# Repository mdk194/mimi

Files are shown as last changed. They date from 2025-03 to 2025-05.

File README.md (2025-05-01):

# mimi keyboard

54 keys split keyboard.
reversible pcb and 3d printed cases

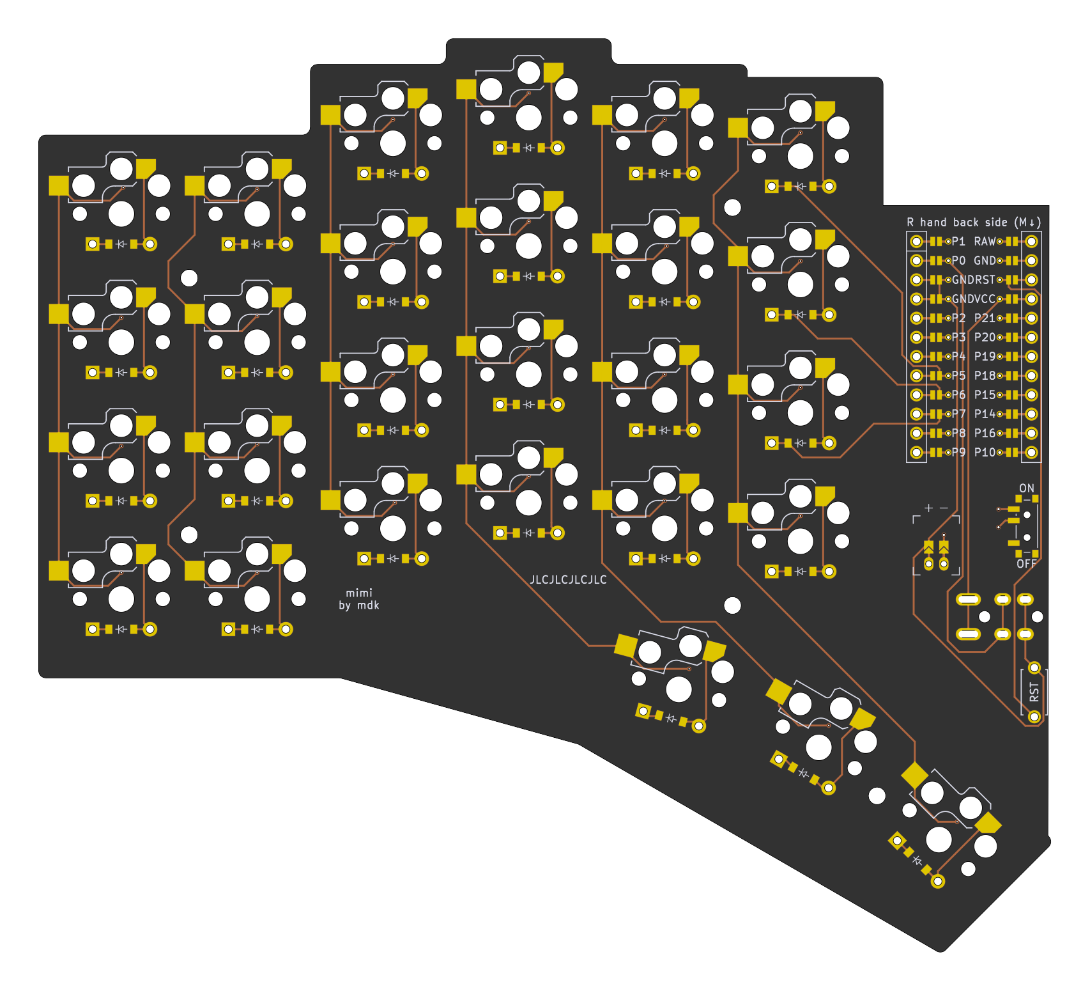
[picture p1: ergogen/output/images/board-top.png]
top pcb

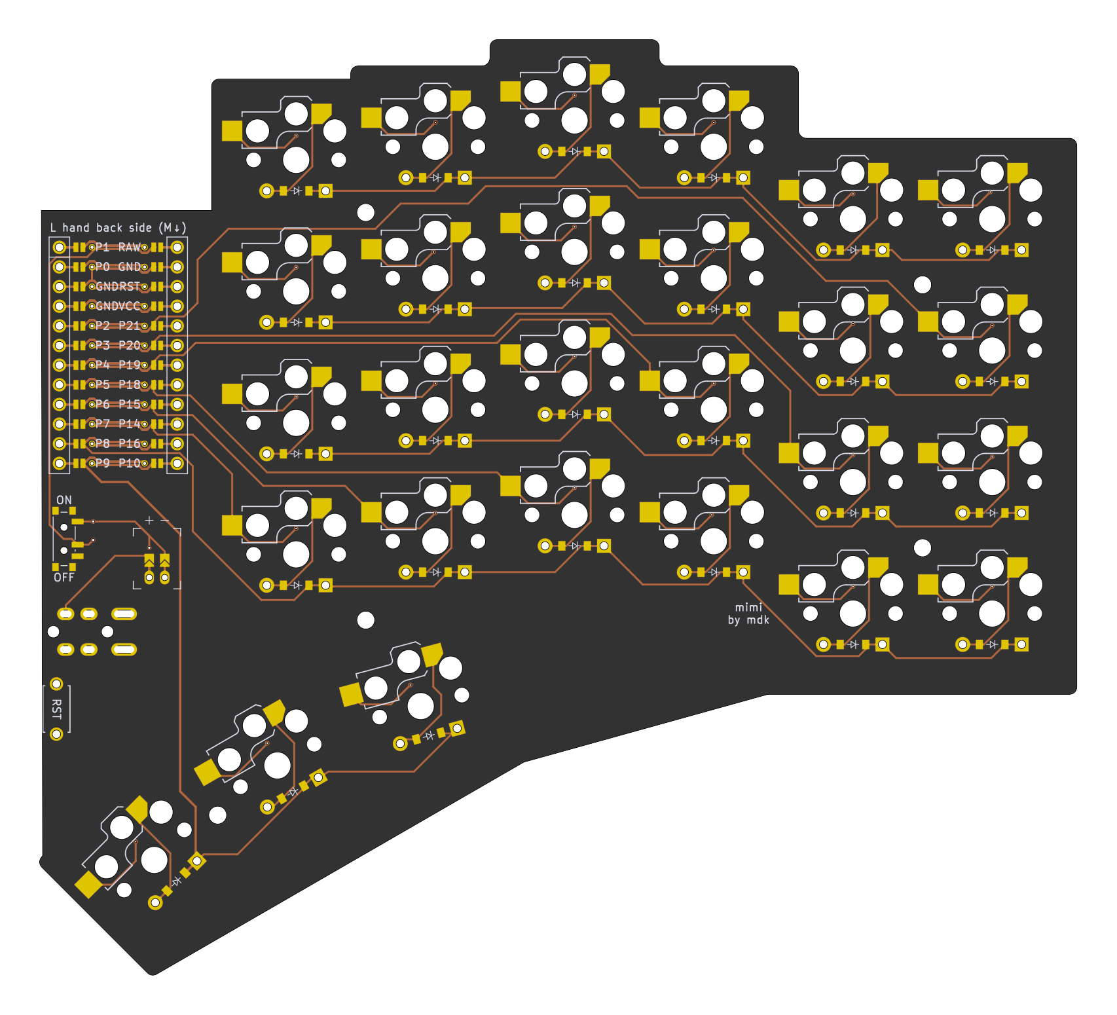
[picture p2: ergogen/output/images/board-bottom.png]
bottom pcb


# ZMK
- main branch: left side as master
- dongle branch: include config for dongle

# TODO
- qmk firmware
- test trrs socket

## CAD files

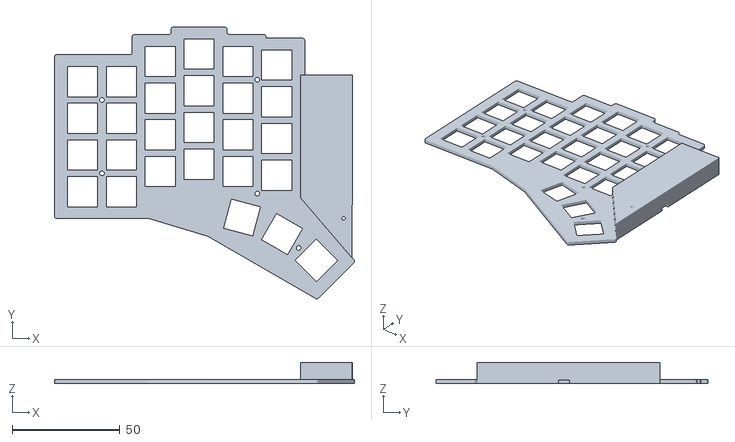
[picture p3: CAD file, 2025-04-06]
cases/wl_top.stl
139.0 x 125.9 x 9.80

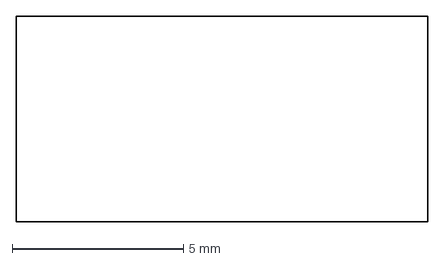
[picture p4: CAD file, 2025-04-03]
output/outlines/usb.dxf
12.0 x 6.00 mm

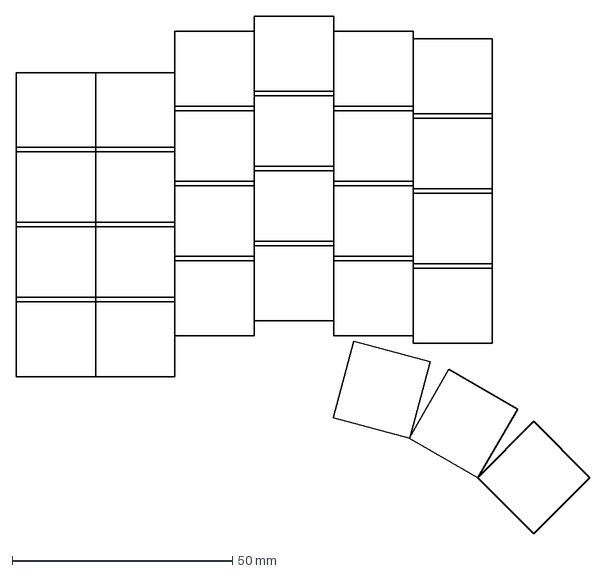
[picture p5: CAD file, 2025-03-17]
output/points/demo.dxf
130.1 x 117.3 mm

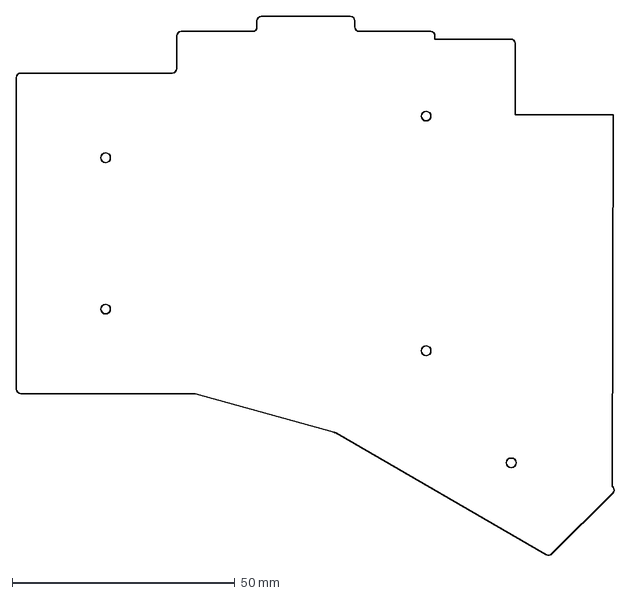
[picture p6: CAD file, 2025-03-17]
output/outlines/pcb.dxf
134.3 x 121.2 mm

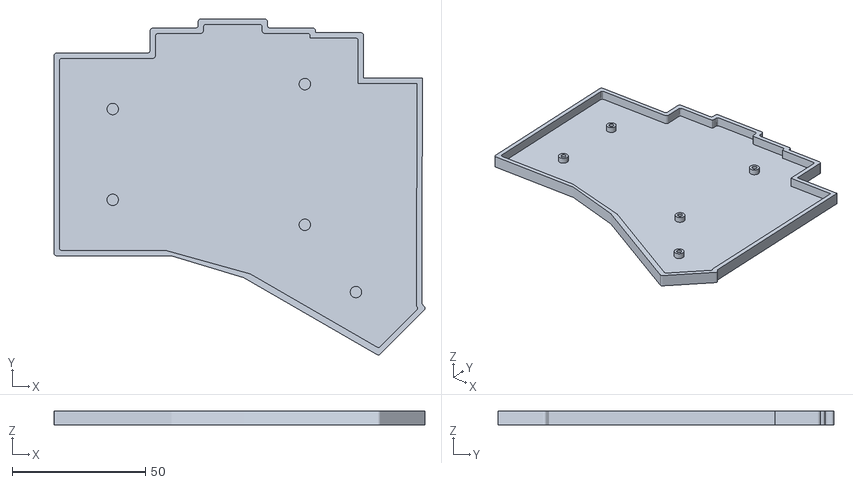
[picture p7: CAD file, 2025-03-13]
cases/bottom.stl
139.0 x 125.9 x 5.20

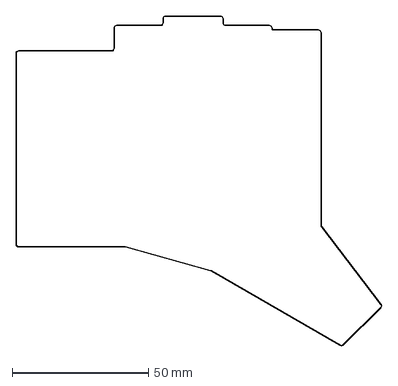
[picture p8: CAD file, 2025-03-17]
output/outlines/base.dxf
134.3 x 121.2 mm

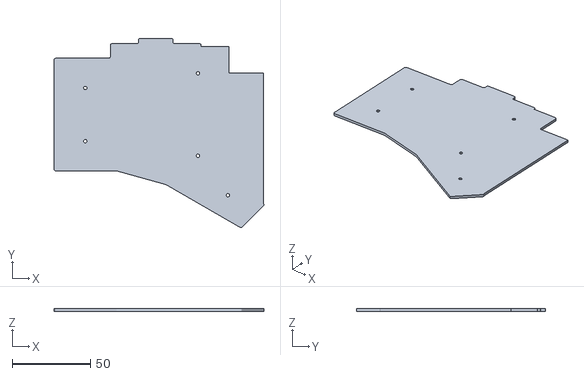
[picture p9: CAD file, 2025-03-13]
cases/pcb.stl
134.2 x 121.1 x 1.60

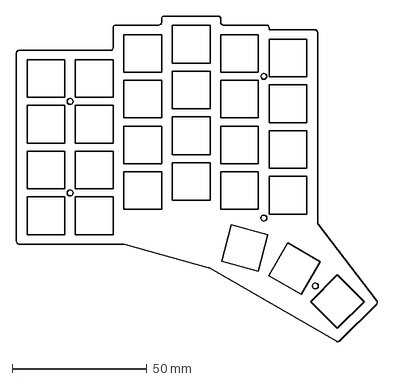
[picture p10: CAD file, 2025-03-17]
output/outlines/top_plate.dxf
134.3 x 121.2 mm

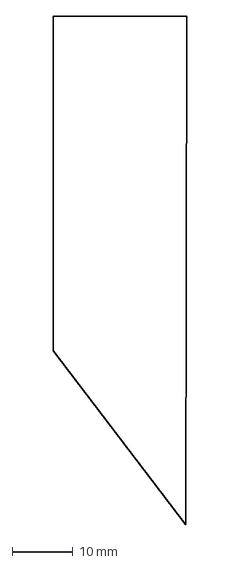
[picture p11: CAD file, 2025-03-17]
output/outlines/controller_area.dxf
22.0 x 83.7 mm

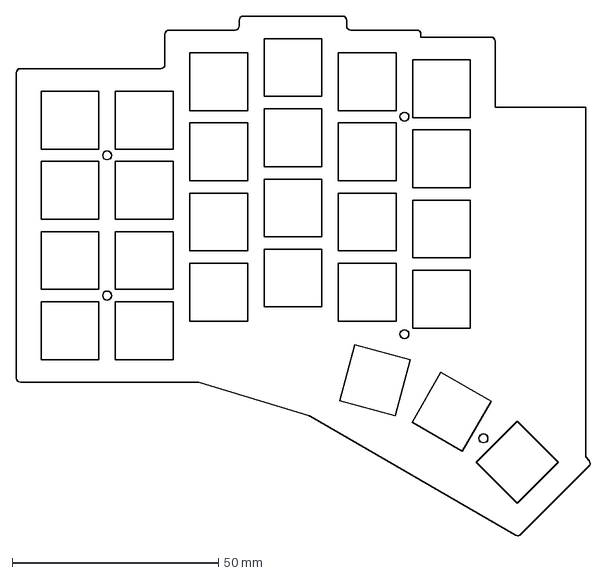
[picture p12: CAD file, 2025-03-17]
output/outlines/top_case.dxf
139.1 x 126.0 mm

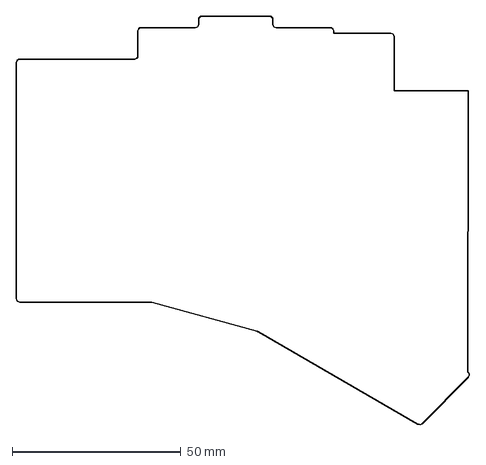
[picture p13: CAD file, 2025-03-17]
output/outlines/bottom_case.dxf
134.3 x 121.2 mm

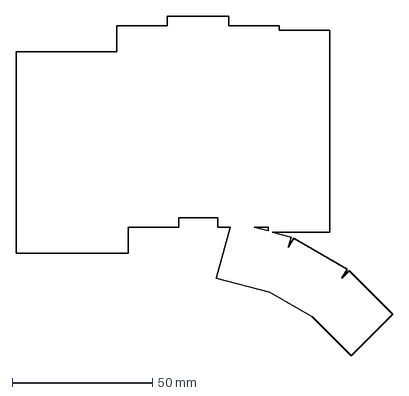
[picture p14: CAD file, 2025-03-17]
output/outlines/raw.dxf
134.6 x 121.3 mm

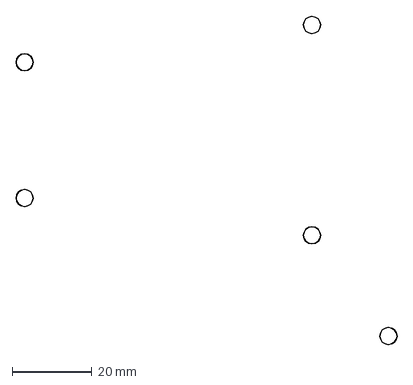
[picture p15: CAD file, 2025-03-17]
output/outlines/standoff.dxf
95.4 x 82.2 mm

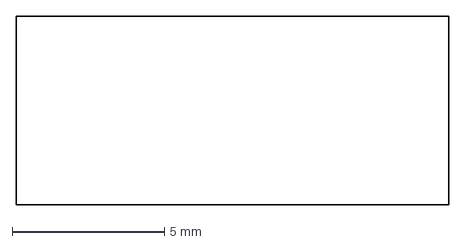
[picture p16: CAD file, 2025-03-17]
output/outlines/trrs.dxf
14.2 x 6.20 mm

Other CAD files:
cases/top.stl
output/outlines/inner_top_cover_area.dxf
output/outlines/xlbase.dxf
output/outlines/xlbottom_case.dxf
output/outlines/power.dxf
output/outlines/screw_holes.dxf
output/outlines/switches.dxf
output/outlines/top_cover_area.dxf
output/outlines/xlcontroller_area.dxf
output/outlines/xlpcb.dxf

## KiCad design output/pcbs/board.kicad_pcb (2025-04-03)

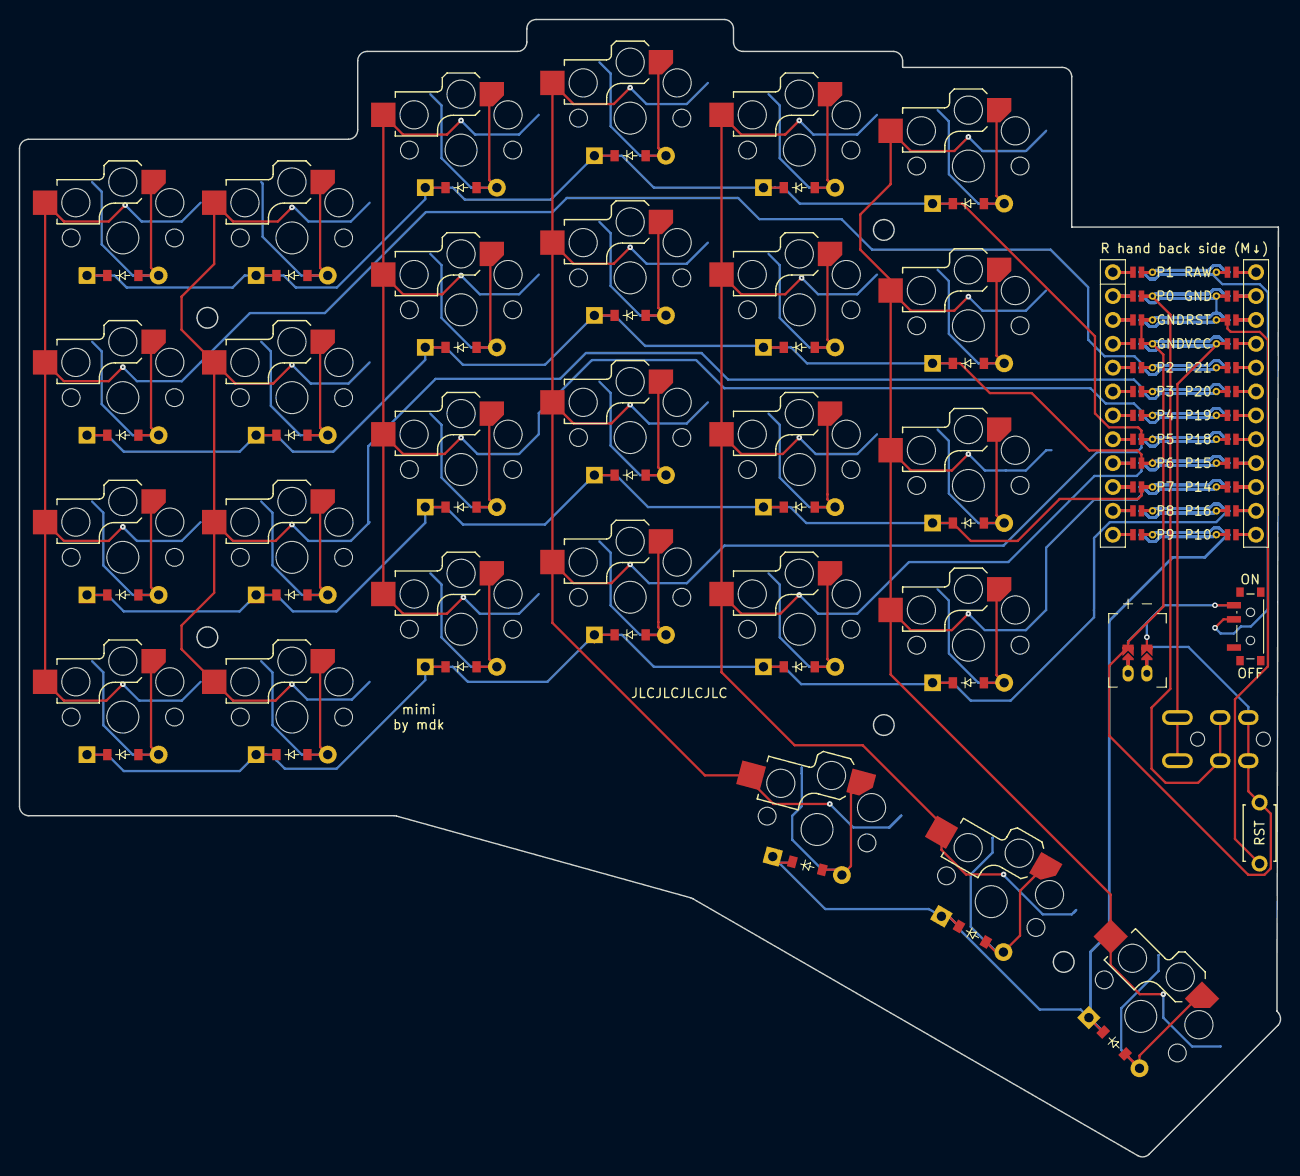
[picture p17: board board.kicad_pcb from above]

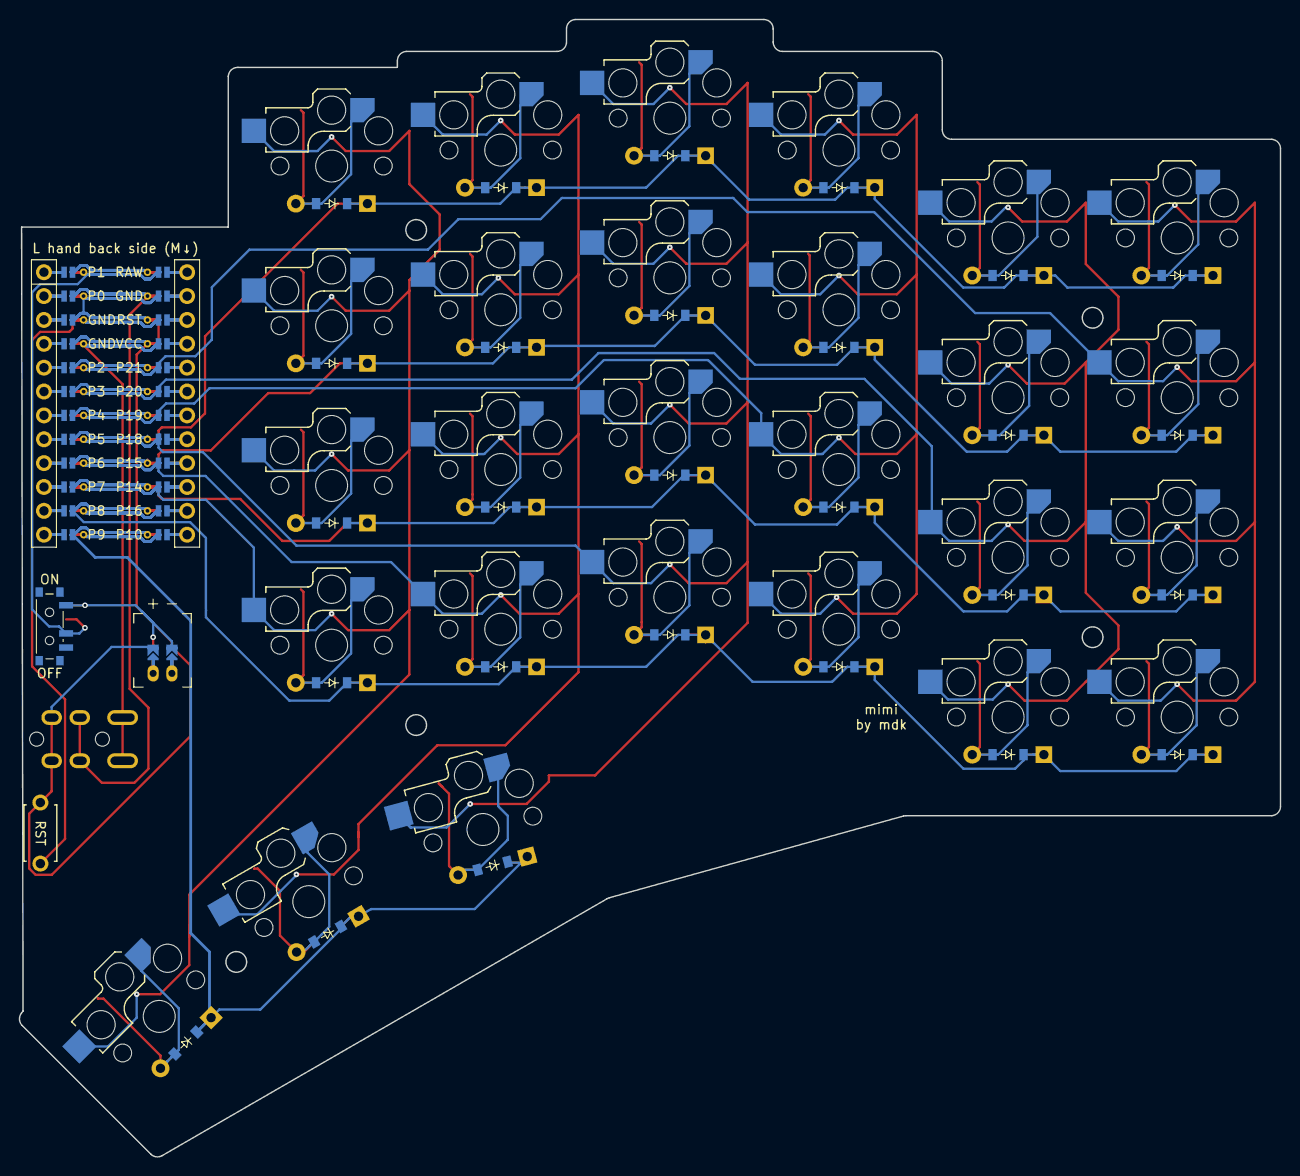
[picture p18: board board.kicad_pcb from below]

Board: 2 copper layers, 134.2 x 121.1 mm, 59 parts (27 on the bottom side), 46 nets.

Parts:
D1, D2, D3, D4, D5, D6, D7, D8, D9, D10, D11, D12, D13, D14, D15, D16, D17, D18, D19, D20, D21, D22, D23, D24, D25, D26, D27: diode_tht_sod123
JST1: battery_connector_jst_ph_2
MCU1: mcu_nice_nano
PWR1: power_switch_smd_side
RST1: reset_switch_tht_top
S1, S2, S3, S4, S5, S6, S7, S8, S9, S10, S11, S12, S13, S14, S15, S16, S17, S18, S19, S20, S21, S22, S23, S24, S25, S26, S27: switch_choc_v1_v2
TRRS1: trrs_pj320a (reversible, symmetric)

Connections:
BAT_P: JST1.1, PWR1.1, PWR1.3
GND: JST1.2, MCU1.102, MCU1.121, MCU1.122, RST1.2, TRRS1.2
JST1_1: JST1.11, JST1.21, JST1.31
JST1_2: JST1.12, JST1.22, JST1.32
P0: MCU1.123, TRRS1.3
P5: D4.1, D8.1, D12.1, D16.1, D20.1, D24.1, MCU1.117
P6: D3.1, D7.1, D11.1, D15.1, D19.1, D23.1, MCU1.116
P7: D2.1, D6.1, D10.1, D14.1, D18.1, D22.1, MCU1.115
P8: D1.1, D5.1, D9.1, D13.1, D17.1, D21.1, MCU1.114
P9: D25.1, D26.1, D27.1, MCU1.113
P14: MCU1.110, S21.2, S22.2, S23.2, S24.2, S27.2
P15: MCU1.109, S17.2, S18.2, S19.2, S20.2, S26.2
P18: MCU1.108, S13.2, S14.2, S15.2, S16.2, S25.2
P19: MCU1.107, S9.2, S10.2, S11.2, S12.2
P20: MCU1.106, S5.2, S6.2, S7.2, S8.2
P21: MCU1.105, S1.2, S2.2, S3.2, S4.2
RAW: MCU1.101, PWR1.2
RST: MCU1.103, RST1.1
VCC: MCU1.104, TRRS1.4
far_thumb: D27.2, S27.1
home_thumb: D26.2, S26.1
index_bottom: D17.2, S17.1
index_home: D18.2, S18.1
index_number: D20.2, S20.1
index_top: D19.2, S19.1
inner_bottom: D21.2, S21.1
inner_home: D22.2, S22.1
inner_number: D24.2, S24.1
inner_top: D23.2, S23.1
middle_bottom: D13.2, S13.1
middle_home: D14.2, S14.1
middle_number: D16.2, S16.1
middle_top: D15.2, S15.1
near_thumb: D25.2, S25.1
outer_bottom: D1.2, S1.1
outer_home: D2.2, S2.1
outer_number: D4.2, S4.1
outer_top: D3.2, S3.1
pinky_bottom: D5.2, S5.1
pinky_home: D6.2, S6.1
pinky_number: D8.2, S8.1
pinky_top: D7.2, S7.1
ring_bottom: D9.2, S9.1
ring_home: D10.2, S10.1
ring_number: D12.2, S12.1
ring_top: D11.2, S11.1

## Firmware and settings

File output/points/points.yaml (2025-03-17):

matrix_outer_bottom:
    x: 50
    'y': -150
    r: 0
    meta:
        stagger: 0
        spread: 18
        splay: 0
        origin:
            - 0
            - 0
        orient: 0
        shift:
            - 0
            - 0
        rotate: 0
        adjust: {}
        width: 18
        height: 18
        padding: 17
        autobind: 10
        skip: false
        asym: both
        colrow: outer_bottom
        name: matrix_outer_bottom
        footprints:
            choc_hotswap:
                type: choc
                params:
                    hotswap: true
                    reverse: true
                    keycaps: true
                nets:
                    from: '=colrow'
                    to: '=column_net'
            diode:
                type: diode
                nets:
                    from: '=colrow'
                    to: '=row_net'
                anchor:
                    shift:
                        - 0
                        - -5
        column_net: P21
        row_net: P8
        zone:
            key:
                padding: 1ky
                spread: 1kx
            columns:
                outer:
                    key:
                        stagger: 0 ky
                        column_net: P21
                    rows: {}
                    name: outer
                pinky:
                    key:
                        stagger: 0 ky
                        column_net: P20
                    rows: {}
                    name: pinky
                ring:
                    key:
                        stagger: 0.55 ky
                        column_net: P19
                    rows: {}
                    name: ring
                middle:
                    key:
                        stagger: 0.2 ky
                        column_net: P18
                    rows: {}
                    name: middle
                index:
                    key:
                        stagger: '-0.2 ky'
                        column_net: P15
                    rows: {}
                    name: index
                inner:
                    key:
                        stagger: '-0.1 ky'
                        column_net: P14
                    rows: {}
                    name: inner
            rows:
                bottom:
                    row_net: P8
                home:
                    row_net: P7
                top:
                    row_net: P6
                number:
                    row_net: P5
            name: matrix
        col:
            key:
                stagger: 0 ky
                column_net: P21
            rows: {}
            name: outer
        row: bottom
        bind:
            - 10
            - 10
            - 0
            - 0
matrix_outer_home:
    x: 50
    'y': -133
    r: 0
    meta:
        stagger: 0
        spread: 18
        splay: 0
        origin:
            - 0
            - 0
        orient: 0
        shift:
            - 0
            - 0
        rotate: 0
        adjust: {}
        width: 18
        height: 18
        padding: 17
        autobind: 10
        skip: false
        asym: both
        colrow: outer_home
        name: matrix_outer_home
        footprints:
            choc_hotswap:
                type: choc
                params:
                    hotswap: true
                    reverse: true
                    keycaps: true
                nets:
                    from: '=colrow'
                    to: '=column_net'
            diode:
                type: diode
                nets:
                    from: '=colrow'
                    to: '=row_net'
                anchor:
                    shift:
                        - 0
                        - -5
        column_net: P21
        row_net: P7
        zone:
            key:
                padding: 1ky
                spread: 1kx
            columns:
                outer:
                    key:
                        stagger: 0 ky
                        column_net: P21
                    rows: {}
                    name: outer
                pinky:
                    key:
                        stagger: 0 ky
                        column_net: P20
                    rows: {}
                    name: pinky
                ring:
                    key:
                        stagger: 0.55 ky
                        column_net: P19
                    rows: {}
                    name: ring
                middle:
                    key:
                        stagger: 0.2 ky
                        column_net: P18
                    rows: {}
                    name: middle
                index:
                    key:
                        stagger: '-0.2 ky'
                        column_net: P15
                    rows: {}
                    name: index
                inner:
                    key:
                        stagger: '-0.1 ky'
                        column_net: P14
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

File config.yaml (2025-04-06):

meta:
  engine: 4.1.0
  name: mimi
  version: 0.1
  author: mdk
units:
  kx: cx
  ky: cy
  # padding
  px: kx + 4
  py: ky + 4
  dpx: kx + 8
  dpy: ky + 8

  # Physical measures
  screw_radius: 1.1 # M2 screws
  screw_diameter: screw_radius * 2
  screw_head_radius: 2.05
  screw_head_diameter: screw_head_radius * 2
  spacer_radius: 2.15 # M2 standoffs
  spacer_diameter: spacer_radius * 2
  fillet_radius: 0.5
  pwr_trace_width: 0.25
  gnd_trace_width: 0.25
  signal_trace_width: 0.15

points:
  key:
    footprints:
      choc_hotswap:
        type: choc
        params:
          hotswap: true
          reverse: true
          keycaps: true
        nets:
          from: =colrow
          to: =column_net
      diode:
        type: diode
        nets:
          from: =colrow
          to: =row_net
        anchor:
          shift: [0, -5]
  zones:
    matrix:
      anchor:
        rotate: 0
        shift: [50, -150] # for Kicad
      key:
        padding: 1ky
        spread: 1kx
      columns:
        outer:
          key:
            stagger: 0 ky
            column_net: P21
        pinky:
          key:
            stagger: 0 ky
            column_net: P20
        ring:
          key:
            stagger: 0.55 ky
            column_net: P19
        middle:
          key:
            stagger: 0.2 ky
            column_net: P18
        index:
          key:
            stagger: -0.2 ky
            column_net: P15
        inner:
          key:
            stagger: -0.1 ky
            column_net: P14
      rows:
        bottom:
          row_net: P8
        home:
          row_net: P7
        top:
          row_net: P6
        number:
          row_net: P5
    thumbfan:
      key:
        padding: 1ky
        spread: 1kx
      anchor:
        ref: matrix_inner_bottom
        shift: [-1 kx, -1 ky]
      columns:
        near:
          key:
            splay: -15
            origin: [-0.5 kx, -0.5 ky]
            column_net: P18
        home:
          key:
            splay: -15
            origin: [-0.5 kx, -0.5 ky]
            column_net: P15
        far:
          key:
            splay: -15
            origin: [-0.5 kx, -0.5 ky]
            column_net: P14
      rows:
        thumb:
          row_net: P9
outlines:
  raw:
    - what: rectangle
      where: true
      asym: source
      size: [px, py]
  switches:
    - what: rectangle
      where: true
      asym: source
      size: 14
  controller_area:
    - what: polygon
      operation: stack
      points:
        - ref: matrix_inner_top
          shift: [0.5px, 0.5py]
        - ref: matrix_inner_top
          shift: [0.5px + 22, 0.5py]
        - ref: thumbfan_far_thumb
          shift: [0.5px - 1, 0.5py]
        - ref: matrix_inner_bottom
          shift: [0.5px, -0.5py]
  xlcontroller_area:
    - what: polygon
      operation: stack
      points:
        - ref: matrix_inner_top
          shift: [0.5dpx, 0.5dpy]
        - ref: matrix_inner_top
          shift: [0.5dpx + 22, 0.5dpy]
        - ref: thumbfan_far_thumb
          shift: [0.5dpx - 2, 0.5dpy]
        - ref: matrix_inner_bottom
          shift: [0.5dpx, -0.5dpy]
  top_cover_area:
    - what: polygon
      operation: stack
      points:
        - ref: matrix_inner_top
          shift: [0.5px, 0.5py + 2]
        - ref: matrix_inner_top
          shift: [0.5dpx + 22, 0.5dpy]
        - ref: thumbfan_far_thumb
          shift: [0.5px, 0.5py + 2]
        - ref: matrix_inner_bottom
          shift: [0.5px, -0.5py]
  inner_top_cover_area:
    - what: polygon
      operation: stack
      points:
        - ref: matrix_inner_top
          shift: [0.5px + 2, 0.5py]
        - ref: matrix_inner_top
          shift: [0.5px + 22, 0.5py]
        - ref: thumbfan_far_thumb
          shift: [0.5px - 5, 0.5py + 4]
        - ref: matrix_inner_bottom
          shift: [0.5px + 2, -0.5py + 2]
  base:
    - what: polygon
      operation: stack
      fillet: 1
      points:
        - ref: matrix_outer_number
          shift: [-0.5px, 0.5py]
        - ref: matrix_pinky_number
          shift: [0.5kx - 2, 0.5ky + 2]
        - ref: matrix_ring_number
          shift: [-0.5kx - 2, 0.5ky + 2]
        - ref: matrix_ring_number
          shift: [0.5kx - 2, 0.5ky + 2]
        - ref: matrix_middle_number
          shift: [-0.5kx - 2, 0.5ky + 2]
        - ref: matrix_middle_number
          shift: [0.5kx + 2, 0.5ky + 2]
        - ref: matrix_index_number
          shift: [-0.5kx + 2, 0.5ky + 2]
        - ref: matrix_index_number
          shift: [0.5kx + 2, 0.5ky + 2]
        - ref: matrix_inner_number
          shift: [-0.5kx + 2, 0.5ky + 2]
        - ref: matrix_inner_number
          shift: [0.5px , 0.5py]
        - ref: matrix_inner_bottom
          shift: [0.5px, -0.5py]
        - ref: thumbfan_far_thumb
          shift: [0.5px, 0.5py]
        - ref: thumbfan_far_thumb
          shift: [0.5px, -0.5py]
        - ref: thumbfan_near_thumb
          shift: [-0.5px, -0.5py]
        - ref: matrix_pinky_bottom
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

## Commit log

2025-03-13 routed board
    [board.kicad_pcb]
2025-03-13 add gerbers files
    [board-B_Cu.gbl, board-B_Mask.gbs, board-B_Silkscreen.gbo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]
2025-03-17 fix trrs pin
2025-03-17 fix trrs routing
    [base.dxf, board.dsn, board.kicad_pcb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]
2025-03-17 re-plot gerbers and images
    [board-B_Cu.gbl, board-B_Mask.gbs, board-B_Silkscreen.gbo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]
2025-04-03 cases: fix mcu usb port size
    [top.stl]
2025-04-03 trrs: enable back symmetric + serial pin
    [board-B_Cu.gbl, board-B_Mask.gbs, board-B_Silkscreen.gbo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]
2025-04-06 add wireless top case, add reset button hole
    [wl_top.stl]
2025-04-25 zmk: report battery for both side
2025-05-31 keymap: use combo for brackets
2025-06-18 keymap: disable brackets combo
2026-05-25 fix: update board to nice_nano@2.0.0
